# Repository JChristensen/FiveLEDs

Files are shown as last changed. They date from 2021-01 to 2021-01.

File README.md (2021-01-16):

# Five LEDs Puzzle
https://github.com/JChristensen/FiveLEDs  
README file  
Jack Christensen  
Jan-2021

## License
  
Five LEDs Puzzle by Jack Christensen and the original project by David Johnson-Davies are both licensed under under a [Creative Commons Attribution 4.0 International License](http://creativecommons.org/licenses/by/4.0/).

See the original project at:  
https://github.com/technoblogy/five-leds-puzzle  
http://www.technoblogy.com/show?3EL5

## Introduction
This is just my spin on David Johnson-Davies' Five LEDs Puzzle. The [circuit](https://raw.githubusercontent.com/JChristensen/FiveLEDs/master/extras/schematic.png) is modified slightly, to use an ATtiny84A microcontroller, and the [PC board design](https://raw.githubusercontent.com/JChristensen/FiveLEDs/master/extras/board.png) is new, to accommodate SMT components and an AA battery holder.

## Instructions
The object of the puzzle is to get all the LEDs to remain lit. Each LED lights up briefly when the corresponding button below it is pressed, but an LED only stays lit under certain conditions; to solve the puzzle you need to work out what the rule is.

The puzzle can be solved by pressing one button at a time; there is no benefit in pressing combinations. To return the puzzle to the start, with all LEDs off, press the RESET button.

If no button is pressed for 30 seconds, the puzzle will automatically turn itself off. Press any button to turn it back on. The LEDs will then be in the same state as when it turned off.

## Circuit design
A bill of materials is available at [Mouser Electronics](https://www.mouser.com/ProjectManager/ProjectDetail.aspx?AccessID=cfd9324946) and also in [this repo](https://github.com/JChristensen/FiveLEDs/blob/master/extras/bom.csv).  

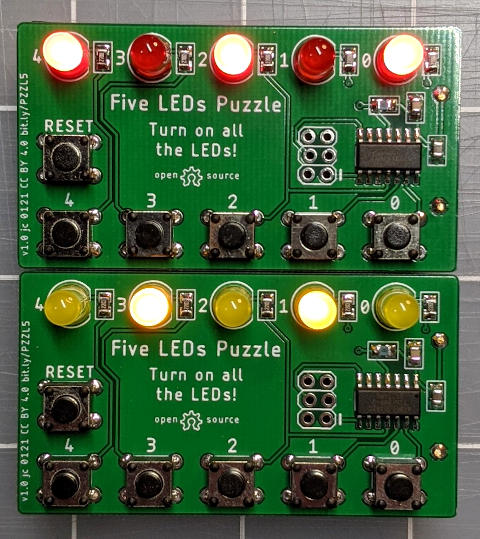
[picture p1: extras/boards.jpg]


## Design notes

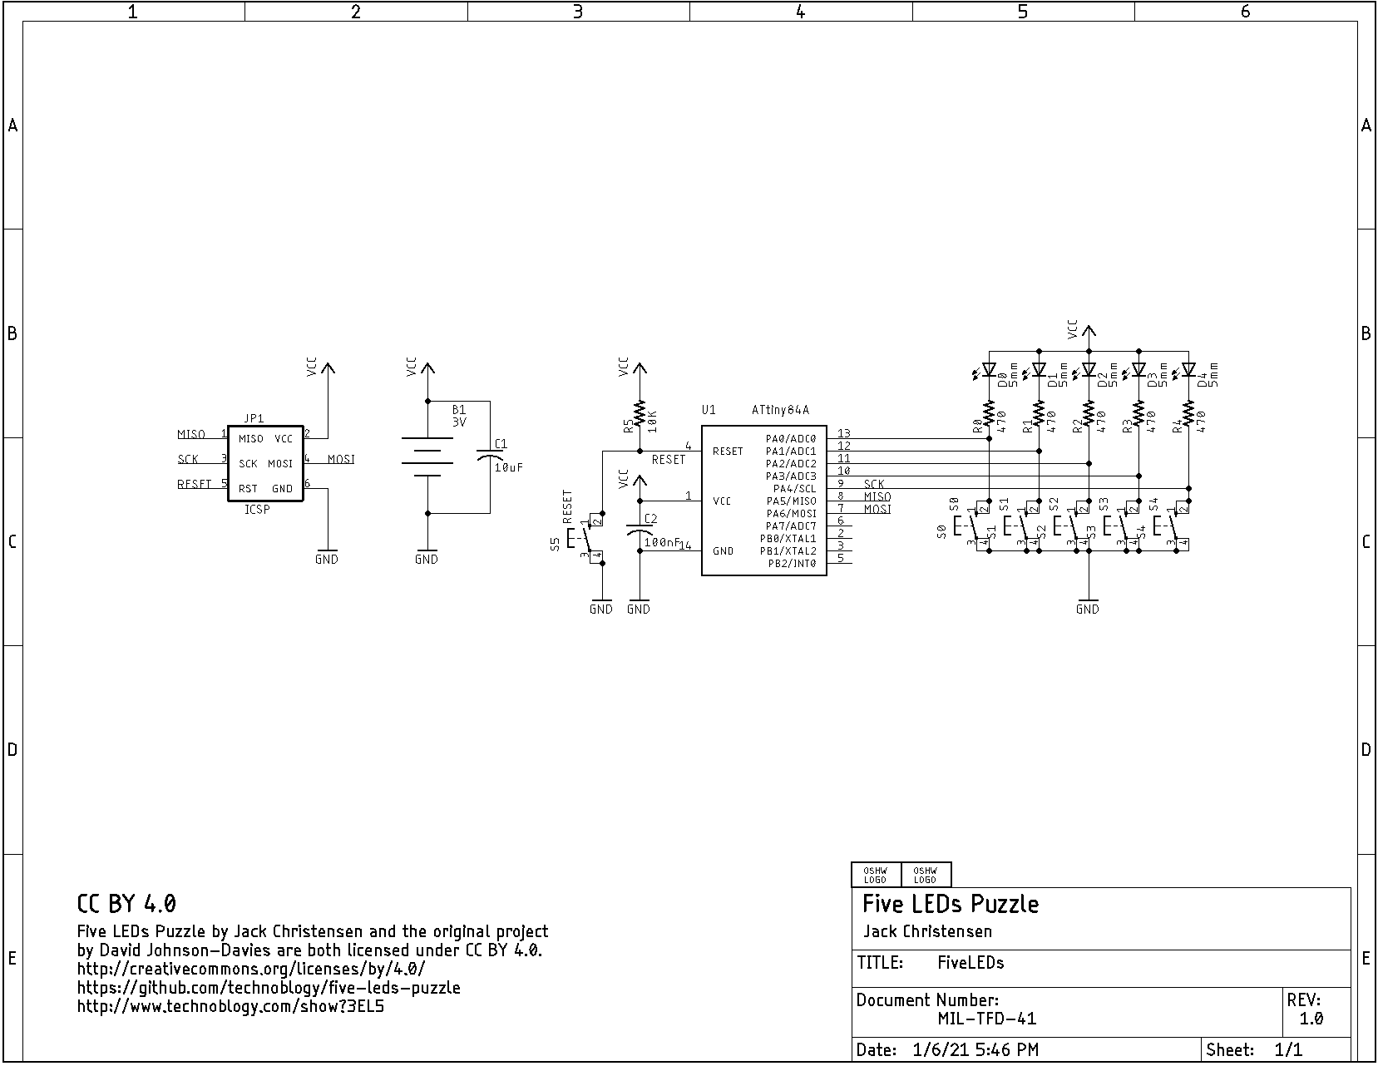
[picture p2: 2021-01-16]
extras/schematic.png

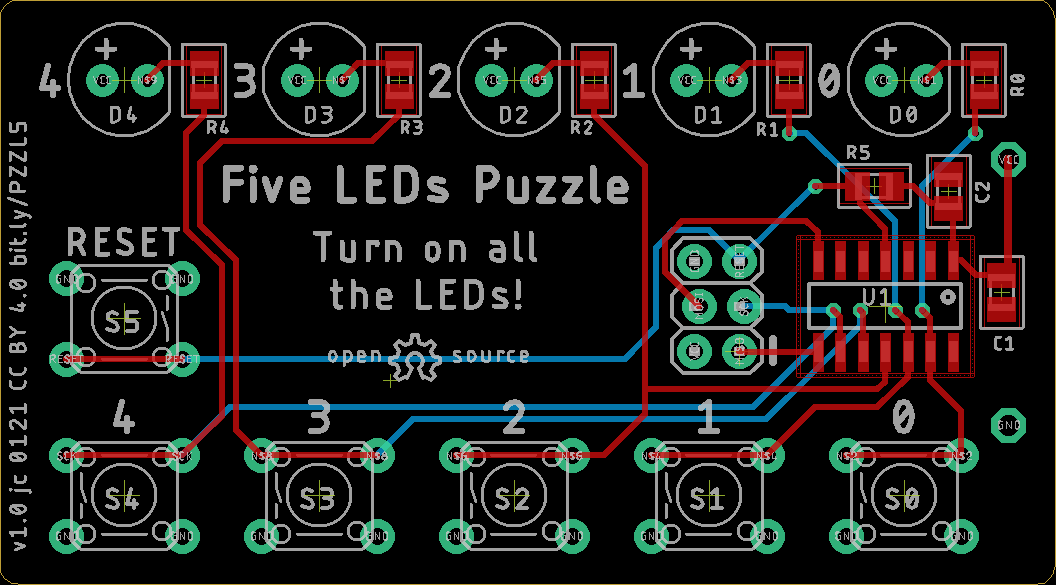
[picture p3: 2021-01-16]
extras/board.png

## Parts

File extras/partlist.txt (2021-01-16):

Partlist

Exported from FiveLEDs.sch at 1/6/21 11:22 PM

EAGLE Version 9.6.2 Copyright (c) 1988-2020 Autodesk, Inc.

Assembly variant: 

Part     Value          Device                Package                Library  Sheet

B1       3V             BATTERY-2AANOHOLES    KEYSTONE-2462-NO-HOLES _jc      1
C1       10uF           C-USM0805             M0805                  _jc      1
C2       100nF          C-USM0805             M0805                  _jc      1
D0       5mm            LED5MM                LED5MM                 _jc      1
D1       5mm            LED5MM                LED5MM                 _jc      1
D2       5mm            LED5MM                LED5MM                 _jc      1
D3       5mm            LED5MM                LED5MM                 _jc      1
D4       5mm            LED5MM                LED5MM                 _jc      1
JP1      ICSP           AVR_SPI_PRG_62X3_LOCK 2X3_LOCK               _jc      1
R0       220            R-US_M0805            M0805                  _jc      1
R1       220            R-US_M0805            M0805                  _jc      1
R2       220            R-US_M0805            M0805                  _jc      1
R3       220            R-US_M0805            M0805                  _jc      1
R4       220            R-US_M0805            M0805                  _jc      1
R5       10K            R-US_M0805            M0805                  _jc      1
S0       S0             10-XXOCT              B3F-10XXOCT            _jc      1
S1       S1             10-XXOCT              B3F-10XXOCT            _jc      1
S2       S2             10-XXOCT              B3F-10XXOCT            _jc      1
S3       S3             10-XXOCT              B3F-10XXOCT            _jc      1
S4       S4             10-XXOCT              B3F-10XXOCT            _jc      1
S5       RESET          10-XXOCT              B3F-10XXOCT            _jc      1
U1       ATtiny84A      ATTINYX4SO14          SO14                   _jc      1

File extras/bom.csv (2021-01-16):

Five LEDs Puzzle
Bill of materials
https://github.com/JChristensen/FiveLEDs
https://www.mouser.com/ProjectManager/ProjectDetail.aspx?AccessID=cfd9324946
Part nbr | Qty | Description | Mouser part nbr | Mfr part nbr | Manufacturer
B1 | 1 | Cylindrical Battery Contacts, Clips, Holders & Springs 2 CELL AA PC HOLDER | 534-2462 | 2462 | Keystone Electronics
C1 | 1 | Multilayer Ceramic Capacitors MLCC - SMD/SMT 10uF+/-10% 10V X5R 2012 | 187-CL21A106KPFNNNG | CL21A106KPFNNNG | Samsung Electro-Mechanics
C2 | 1 | Multilayer Ceramic Capacitors MLCC - SMD/SMT 50V .1uF X7R 0805 10%TOL | 581-08055C104K | 08055C104KAT2A | AVX
D0-D4 | 5 | Standard LEDs - Through Hole RED DIFFUSED | 604-WP7113SRD/E | WP7113SRD/E | Kingbright
R0-R4 | 5 | Thick Film Resistors - SMD SMD 1/4 watts 220ohms 1% | 660-RK73H2ATTD2200F | RK73H2ATTD2200F | KOA Speer
R5 | 1 | Thick Film Resistors - SMD 1/4W 10K OHM 1% | 660-RK73H2ATTDD1002F | RK73H2ATTDD1002F | KOA Speer
S0-S5 | 6 | Tactile Switches 6X6 Flat 5mm Btn Force 150g w/out Grd | 653-B3F-1022 | B3F-1022 | Omron
U1 | 1 | 8-bit Microcontrollers - MCU 20MHz Ind. Grade | 556-ATTINY84A-SSU | ATTINY84A-SSU | Microchip

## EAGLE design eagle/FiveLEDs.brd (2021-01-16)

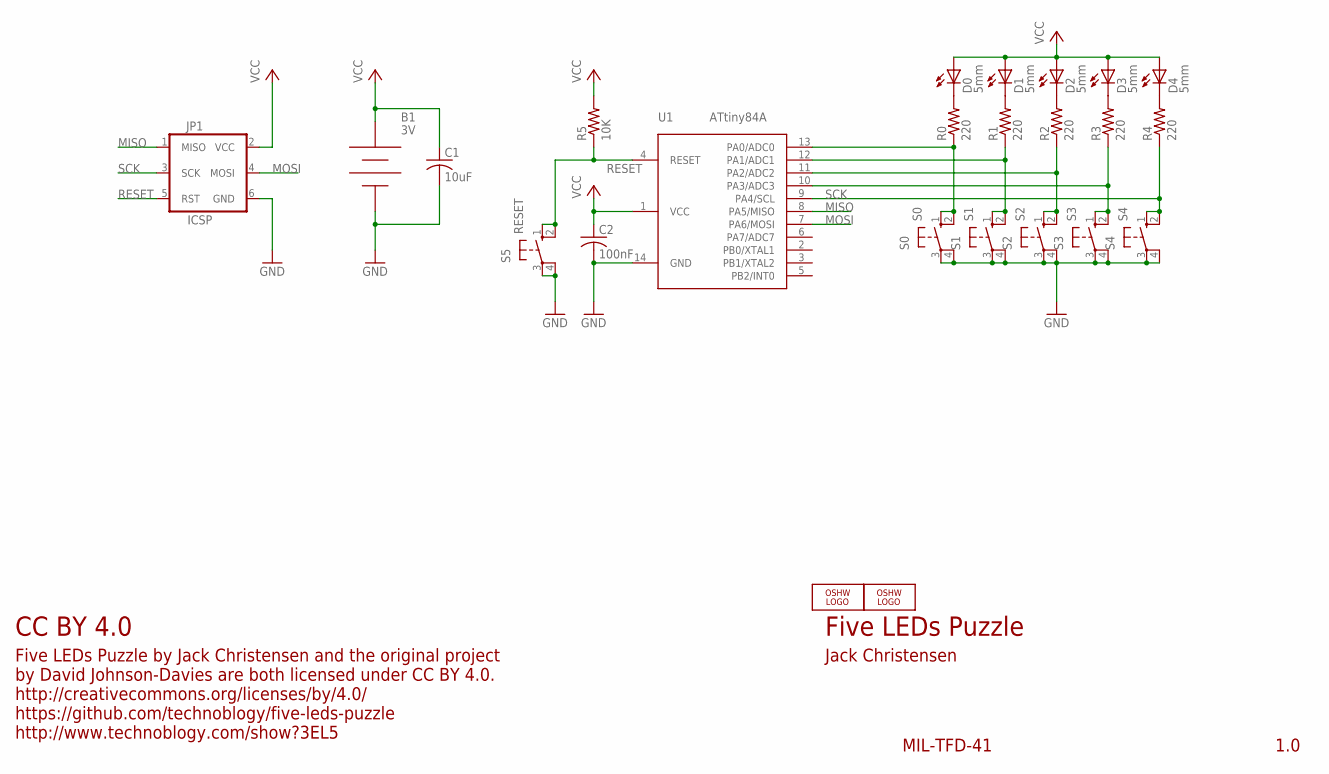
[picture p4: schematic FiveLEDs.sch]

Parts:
B1: 3V; KEYSTONE-2462-NO-HOLES
C1: 10uF; M0805
C2: 100nF; M0805
D0, D1, D2, D3, D4: 5mm; LED5MM
JP1: ICSP; 2X3_LOCK
LOGO1: OSHW_LOGO_8MILX0150-NT; OSHW_8X150_NOTEXT
LOGO3: OSHW_LOGO_8MILX0100-NT; OSHW_8X100_NOTEXT
R0, R1, R2, R3, R4: 220; M0805
R5: 10K; M0805
S0: S0; B3F-10XXOCT
S1: S1; B3F-10XXOCT
S2: S2; B3F-10XXOCT
S3: S3; B3F-10XXOCT
S4: S4; B3F-10XXOCT
S5: RESET; B3F-10XXOCT
U1: ATtiny84A; SO14

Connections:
GND: B1.NEG, C1.2, C2.2, JP1.6 (GND), S0.3, S0.4 (P1), S1.3, S1.4 (P1), S2.3, S2.4 (P1), S3.3, S3.4 (P1), S4.3, S4.4 (P1), S5.3, S5.4 (P1), U1.14 (GND)
MISO: JP1.1 (MISO), U1.8 (PA5/MISO)
MOSI: JP1.4 (MOSI), U1.7 (PA6/MOSI)
unnamed: D0.K (C), R0.2
unnamed: R0.1, S0.1 (S), S0.2 (S1), U1.13 (PA0/ADC0)
unnamed: D1.K (C), R1.2
unnamed: R1.1, S1.1 (S), S1.2 (S1), U1.12 (PA1/ADC1)
unnamed: D2.K (C), R2.2
unnamed: R2.1, S2.1 (S), S2.2 (S1), U1.11 (PA2/ADC2)
unnamed: D3.K (C), R3.2
unnamed: R3.1, S3.1 (S), S3.2 (S1), U1.10 (PA3/ADC3)
unnamed: D4.K (C), R4.2
RESET: JP1.5 (RST), R5.1, S5.1 (S), S5.2 (S1), U1.4 (RESET)
SCK: JP1.3 (SCK), R4.1, S4.1 (S), S4.2 (S1), U1.9 (PA4/SCL)
VCC: B1.POS, C1.1, C2.1, D0.A, D1.A, D2.A, D3.A, D4.A, JP1.2 (VCC), R5.2, U1.1 (VCC)

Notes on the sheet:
Five LEDs Puzzle
Jack Christensen
MIL-TFD-41
1.0
CC BY 4.0
Five LEDs Puzzle by Jack Christensen and the original project by David Johnson-Davies are both licensed under CC BY 4.0. http://creativecommons.org/licenses/by/4.0/ https://github.com/technoblogy/five-leds-puzzle http://www.technoblogy.com/show?3EL5

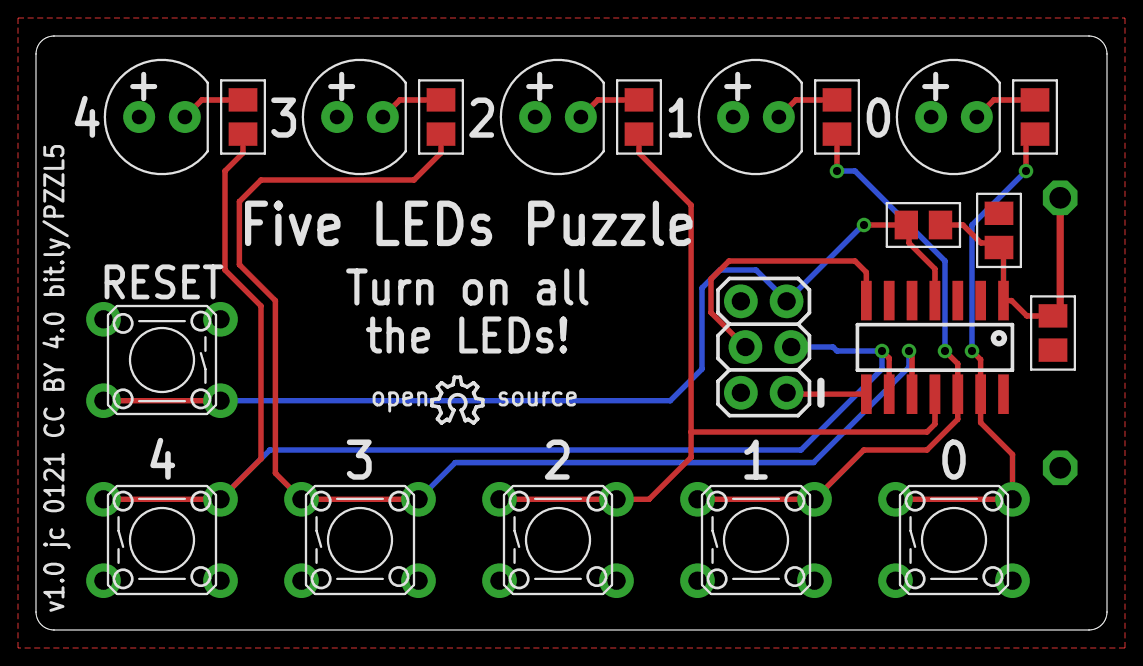
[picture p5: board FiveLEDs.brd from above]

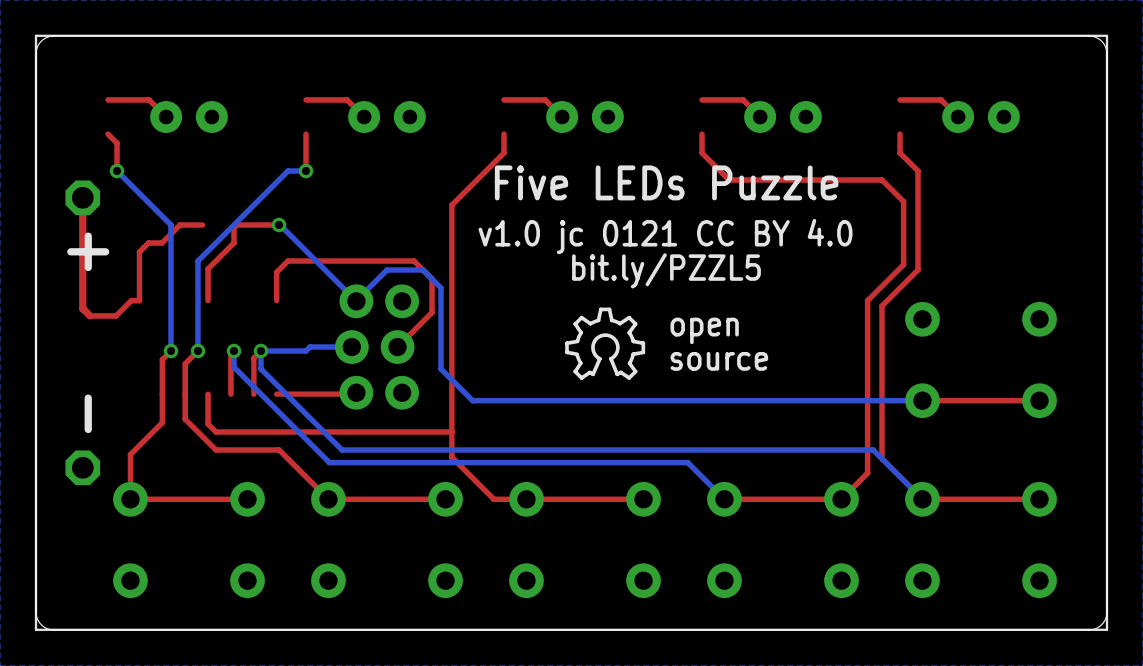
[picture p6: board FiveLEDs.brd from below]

Board: 2 copper layers, 59.5 x 33.0 mm, 24 parts (2 on the bottom side), 15 nets.

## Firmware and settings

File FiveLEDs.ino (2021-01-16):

// Five LEDs Puzzle
// https://github.com/JChristensen/FiveLEDs
// Adapted for ATtiny84A by Jack Christensen, from
// an original project by David Johnson-Davies, see:
// http://www.technoblogy.com/show?3EL5
// https://github.com/technoblogy/five-leds-puzzle
//
// CC BY 4.0
// Licensed under a Creative Commons Attribution 4.0 International license:
// http://creativecommons.org/licenses/by/4.0/
//
// Developed with Arduino 1.8.13
// and ATTinyCore 1.4.1, https://github.com/SpenceKonde/ATTinyCore
// Chip: ATtiny84A (or 44A, 24A)
// Clock: 1MHz internal
// BOD: 1.8V
// Pin Mapping: (don't care)
// LTO: Disabled
// millis(): enabled

#include <avr/sleep.h>

void setup()
{
    // a very small reset light show
    for (int i=0; i<5; i++) {
        DDRA |= 1 << i;
        delay(75);
    }
    for (int i=0; i<5; i++) {
        DDRA &= ~(1 << i);
        delay(75);
    }

    DDRA = 0;               // LEDs off
    PORTA = 0xe0;           // pullups on for unused pins
    PORTB = 0x0f;
    ADCSRA &= ~_BV(ADEN);   // disable ADC to save power
}

constexpr uint32_t timeout {30000};     // 30 seconds

void loop() {
    uint32_t ms = millis();
    while (millis() - ms <= timeout) {
        for (int b=0; b<5; b++) {
            int d = DDRA;
            DDRA = d & ~(1 << b);
            PORTA |= 1 << b;
            delay(1);
            if ( !(PINA & 1 << b) ) {
                while ( !(PINA & 1 << b) );
                PORTA &= ~(1 << b);
                DDRA = d ^ ((!b || (d & ((1<<b)-1)) == 1<<(b-1)) << b);
                ms = millis();
            }
            else {
                PORTA &= ~(1 << b);
                DDRA = d;
            }
            delay(10);
        }
    }

    // go to sleep
    int d = DDRA;                       // save DDRA
    DDRA = 0;                           // LEDs off
    PORTA = 0xFF;                       // pullups on
    set_sleep_mode(SLEEP_MODE_PWR_DOWN);
    sleep_enable();
    GIFR = _BV(PCIF0);                  // clear pin change interrupt flag
    PCMSK0 = _BV(PCINT0) | _BV(PCINT1) | _BV(PCINT2) | _BV(PCINT3) | _BV(PCINT4);
    GIMSK = _BV(PCIE0);                // enable pin change interrupts
    // stop interrupts to ensure the BOD timed sequence executes as required,
    // then turn off the BOD. if the MCU does not have BOD disable
    // capability, then this code has no effect.
    cli();                              
    uint8_t mcucr1 = MCUCR | _BV(BODS) | _BV(BODSE);
    uint8_t mcucr2 = mcucr1 & ~_BV(BODSE);
    MCUCR = mcucr1;
    MCUCR = mcucr2;
    sei();    
    sleep_cpu();                        // go to sleep
    sleep_disable();
    while((PINA & 0x1f) != 0x1f);       // wait for all buttons released
    PORTA = 0xe0;                       // pullups off
    DDRA = d;                           // restore LEDs
    delay(500);
}

// pin change interrupt is just used to wake the mcu
ISR(PCINT0_vect)
{
    GIMSK = 0;      // disable interrupts (only need one to wake up)
    PCMSK0 = 0;
}

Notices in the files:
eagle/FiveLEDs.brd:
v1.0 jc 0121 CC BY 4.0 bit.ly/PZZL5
